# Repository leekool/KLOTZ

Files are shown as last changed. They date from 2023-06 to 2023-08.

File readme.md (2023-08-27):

# KLOTZ EVQWGD001 MOD

**note: This is a modified version of the original KLOTZ PCB that replaces the EC12 rotary encoder with a EVQWD001 'roller wheel' encoder. In its current state the encoder is not reversible and only works on the right side, and there is also no push button support.

huge thank you to [Sadek Baroudi](https://github.com/sadekbaroudi)

TODO: 
- mirror EVQWD001 footprint for use on left side
- add push button support

<picture>
  <source media="(prefers-color-scheme: dark)" srcset="/docs/images/KLOTZ_font_dark.svg">
  <source media="(prefers-color-scheme: light)" srcset="/docs/images/KLOTZ_font_bright.svg">
  KLOTZ logo font
</picture>

# KLOTZ SPLIT KEYBOARD

KLOTZ is a 34 key column-staggered choc split keyboard running [ZMK](https://zmk.dev/). It supports a low profile encoder, three status LEDs on every side and the SplitKB tenting puck.

KLOTZ stacked

KLOTZ

## LAYOUT

KLOTZ layout

## PCB

[Here](/PCB/) you can find the KiCad files and Gerbers for the KLOTZ.

## SWITCHPLATE

And [here](/switchplate/) is the switchplate, which you should use, if you plan to use hotswap sockets.

## KNOB

You can use pretty much any knob, which works with EC12 encoder, but [here](/knob/) you can find one, I designed for the KLOTZ.

## BUILD GUIDE

The build guide for the KLOTZ can be found [here](/docs/buildguide.md).

## FIRMWARE

[ZMK config](https://github.com/GEIGEIGEIST/zmk-config-klotz) for the KLOTZ.

## TRAVELCASE

Since a lot of people use the Amazon basics harddrive case (ZH1510147) for the KLOTZ I thought I should put an (affiliate) link in here. 

[US Amazon link](https://www.amazon.com/gp/product/B00F5CKWBA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)

[German Amazon link](https://www.amazon.de/gp/product/B00F5CKWBA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)

 If you build a KLOTZ I would be pretty happy to see some pictures. And if you want to leave me a tip you can do this [here](https://ko-fi.com/geigeigeist) (but please don't feel pressured)

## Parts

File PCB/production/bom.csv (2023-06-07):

Designator | Footprint | Quantity | Value | LCSC Part #
BT1 | JST_PH_reversible | 1 | Battery_Cell
BT2 | custombatteryconnector | 1 | Battery_Cell
D1, D10, D11, D12, D13, D14, D15, D16, D17, D2, D3, D4, D5, D6, D7, D8, D9 | Diode_SOD123 | 17 | D_Small
JP1, JP2, JP3, JP4 | Jumper | 4 | Device_Jumper_NO_Small
L1, L2, L3 | LED_3mm_reversible | 3 | LED
MH1, MH2, MH3, MH4, MH5 | MountingHole_2.2mm_M2_ISO7380_Pad | 5 | MountingHole
PSW1 | MSK12C02_reversible | 1 | SW_DPDT_x2
R1, R2, R3 | R_1206_DoubleSided | 3 | 220
RSW1 | ResetSW | 1 | SW_Push
SW1, SW10, SW11, SW12, SW13, SW14, SW15, SW16, SW17, SW2, SW3, SW4, SW5, SW6, SW7, SW8, SW9 | Kailh_socket_PG1350_optional_reversible | 17 | MX_SW_HS
SW19 | EVQWGD001 | 1 | EVQWGD001
U1 | ProMicro_v2 | 1 | nice!nano

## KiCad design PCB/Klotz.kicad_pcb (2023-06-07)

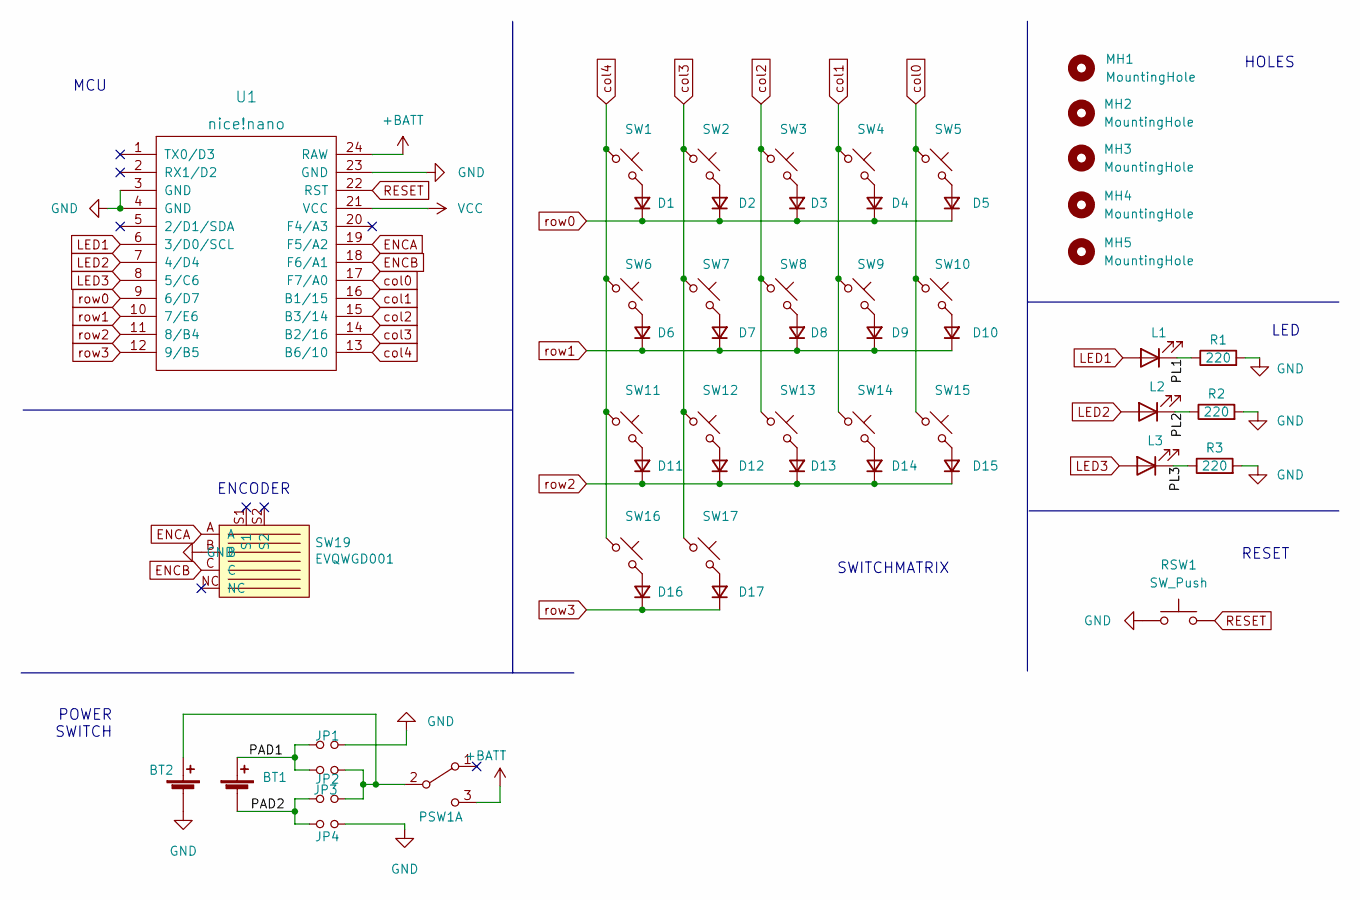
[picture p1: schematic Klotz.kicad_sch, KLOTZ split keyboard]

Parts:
BT1: Battery_Cell; JST_PH_reversible
BT2: Battery_Cell; custombatteryconnector
D1, D2, D3, D4, D5, D6, D7, D8, D9, D10, D11, D12, D13, D14, D15, D16, D17: D_Small; Diode_SOD123
JP1, JP2, JP3, JP4: Device_Jumper_NO_Small; Jumper
L1, L2, L3: LED; LED_3mm_reversible
MH1, MH2, MH3, MH4, MH5: MountingHole; MountingHole_2.2mm_M2_ISO7380_Pad
PSW1: SW_DPDT_x2; MSK12C02_reversible
R1, R2, R3: 220; R_1206_DoubleSided
RSW1: SW_Push; ResetSW
SW1, SW2, SW3, SW4, SW5, SW6, SW7, SW8, SW9, SW10, SW11, SW12, SW13, SW14, SW15, SW16, SW17: MX_SW_HS; Kailh_socket_PG1350_optional_reversible
SW19: EVQWGD001
U1: nice!nano; ProMicro_v2

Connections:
+BATT: PSW1.3 (C), U1.24 (RAW)
/PAD1: BT1.1 (+), JP1.1, JP2.1
/PAD2: BT1.2 (-), JP3.1, JP4.1
/PL1: L1.1 (K), R1.1
/PL2: L2.1 (K), R2.1
/PL3: L3.1 (K), R3.1
ENCA: SW19.A, U1.19 (F5/A2)
ENCB: SW19.C, U1.18 (F6/A1)
GND: BT2.2 (-), JP1.2, JP4.2, R1.2, R2.2, R3.2, RSW1.1, SW19.B, U1.3 (GND), U1.4 (GND), U1.23 (GND)
LED1: L1.2 (A), U1.6 (3/D0/SCL)
LED2: L2.2 (A), U1.7 (4/D4)
LED3: L3.2 (A), U1.8 (5/C6)
unnamed: BT2.1 (+), JP2.2, JP3.2, PSW1.2 (B)
unnamed: D1.2 (A), SW1.2
unnamed: D2.2 (A), SW2.2
unnamed: D3.2 (A), SW3.2
unnamed: D4.2 (A), SW4.2
unnamed: D5.2 (A), SW5.2
unnamed: D6.2 (A), SW6.2
unnamed: D7.2 (A), SW7.2
unnamed: D8.2 (A), SW8.2
unnamed: D9.2 (A), SW9.2
unnamed: D10.2 (A), SW10.2
unnamed: D11.2 (A), SW11.2
unnamed: D12.2 (A), SW12.2
unnamed: D13.2 (A), SW13.2
unnamed: D14.2 (A), SW14.2
unnamed: D15.2 (A), SW15.2
unnamed: D16.2 (A), SW16.2
unnamed: D17.2 (A), SW17.2
RESET: RSW1.2, U1.22 (RST)
VCC: U1.21 (VCC)
col0: SW5.1, SW10.1, SW15.1, U1.17 (F7/A0)
col1: SW4.1, SW9.1, SW14.1, U1.16 (B1/15)
col2: SW3.1, SW8.1, SW13.1, U1.15 (B3/14)
col3: SW2.1, SW7.1, SW12.1, SW17.1, U1.14 (B2/16)
col4: SW1.1, SW6.1, SW11.1, SW16.1, U1.13 (B6/10)
row0: D1.1 (K), D2.1 (K), D3.1 (K), D4.1 (K), D5.1 (K), U1.9 (6/D7)
row1: D6.1 (K), D7.1 (K), D8.1 (K), D9.1 (K), D10.1 (K), U1.10 (7/E6)
row2: D11.1 (K), D12.1 (K), D13.1 (K), D14.1 (K), D15.1 (K), U1.11 (8/B4)
row3: D16.1 (K), D17.1 (K), U1.12 (9/B5)

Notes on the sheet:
SWITCHMATRIX
POWER SWITCH
HOLES
LED
MCU
RESET
ENCODER

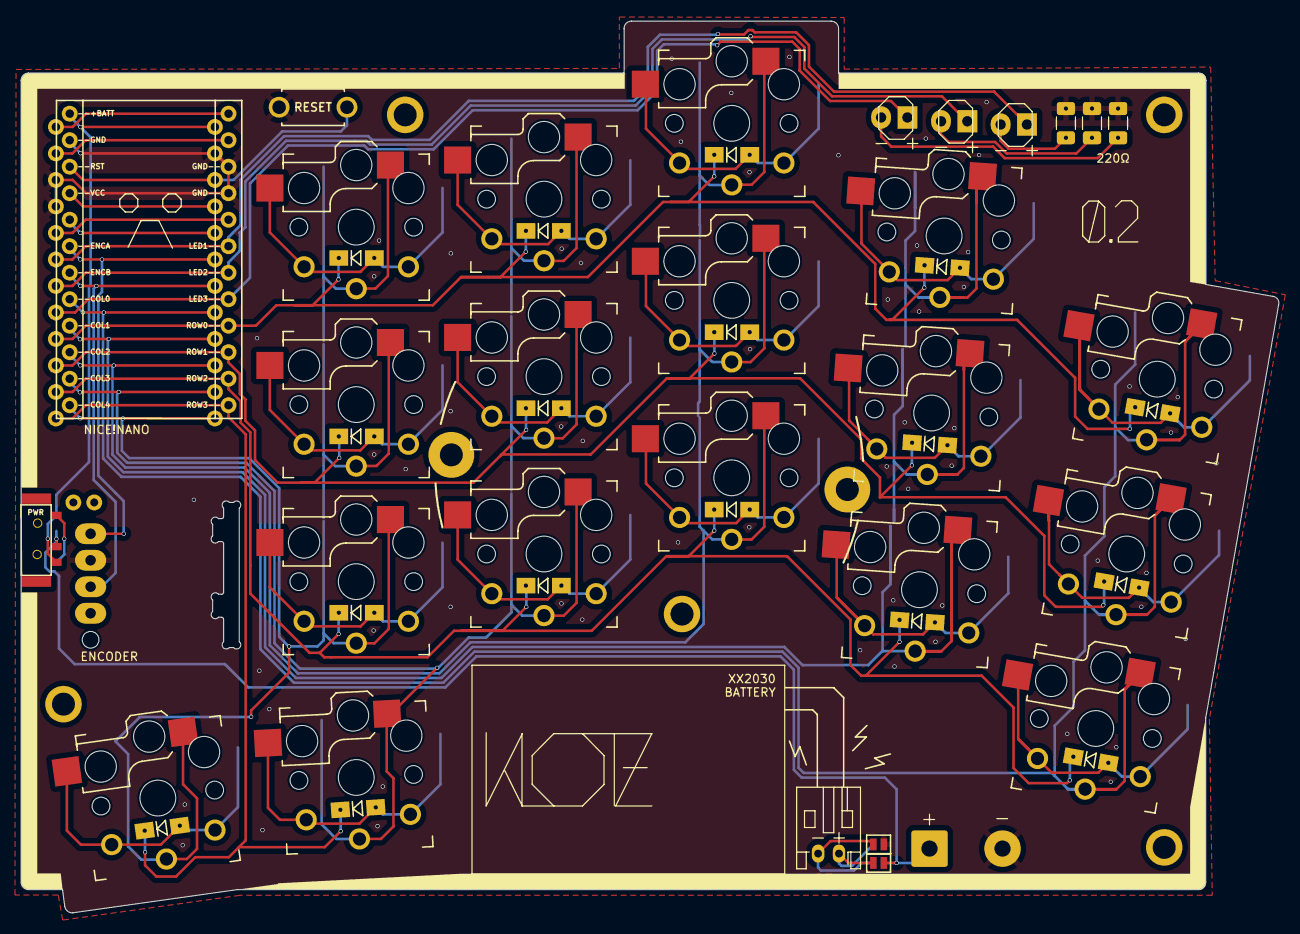
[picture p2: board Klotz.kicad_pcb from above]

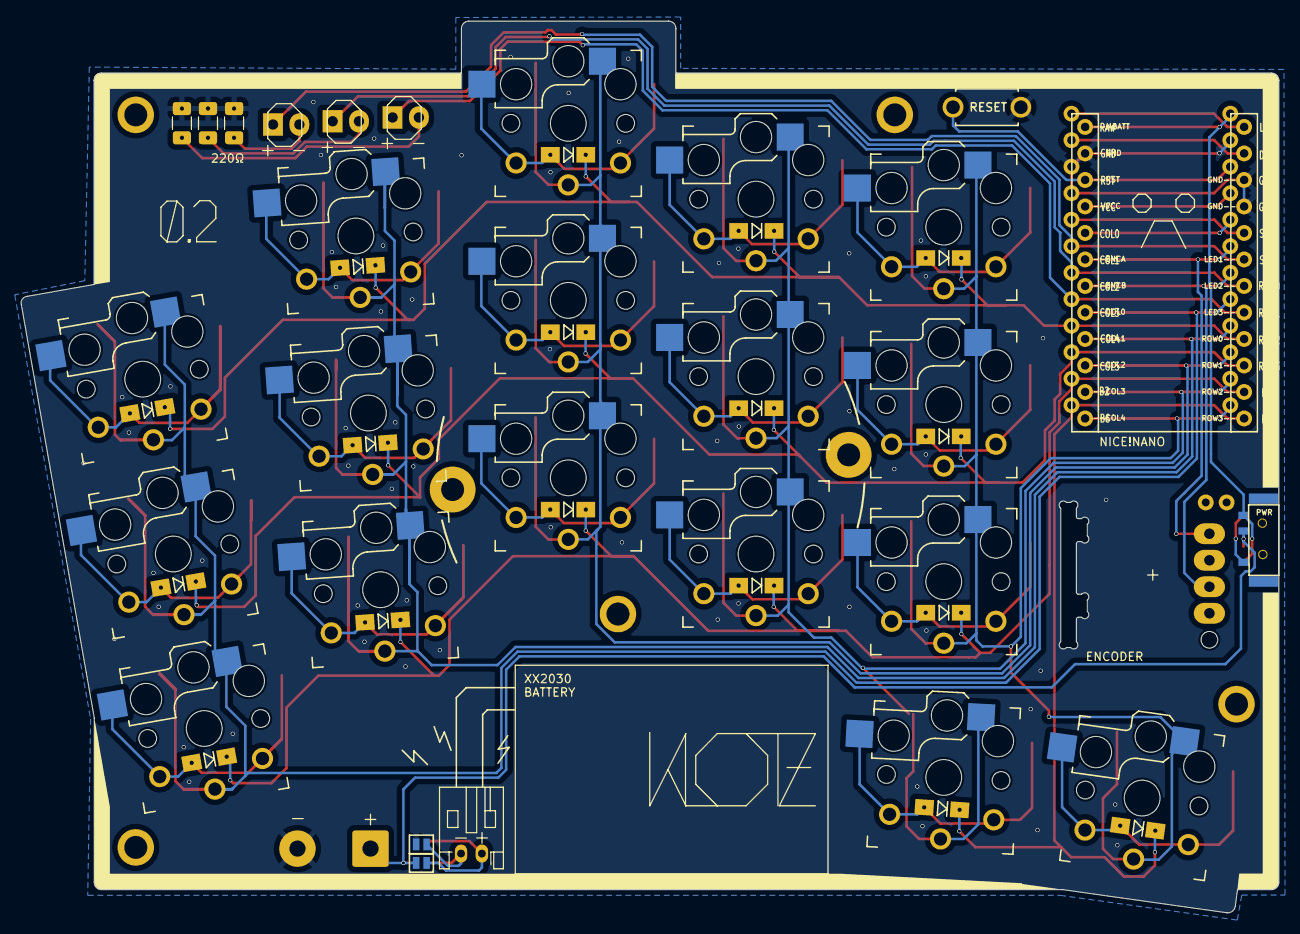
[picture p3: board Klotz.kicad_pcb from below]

Board: 2 copper layers, 120.5 x 85.5 mm, 55 parts (3 on the bottom side), 40 nets.

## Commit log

2023-06-08 pcb gerbers
    [Klotz-B_Cu.gbl, Klotz-B_Mask.gbs, Klotz-B_Paste.gbp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]
2023-06-08 switchplate gerbers
    [Klotz_02_Plate-B_Cu.gbl, Klotz_02_Plate-B_Mask.gbs, Klotz_02_Plate-B_Paste.gbp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]
2023-06-08 gerber zips
